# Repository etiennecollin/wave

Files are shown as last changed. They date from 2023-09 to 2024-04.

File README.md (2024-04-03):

# Wave <!-- omit from toc -->

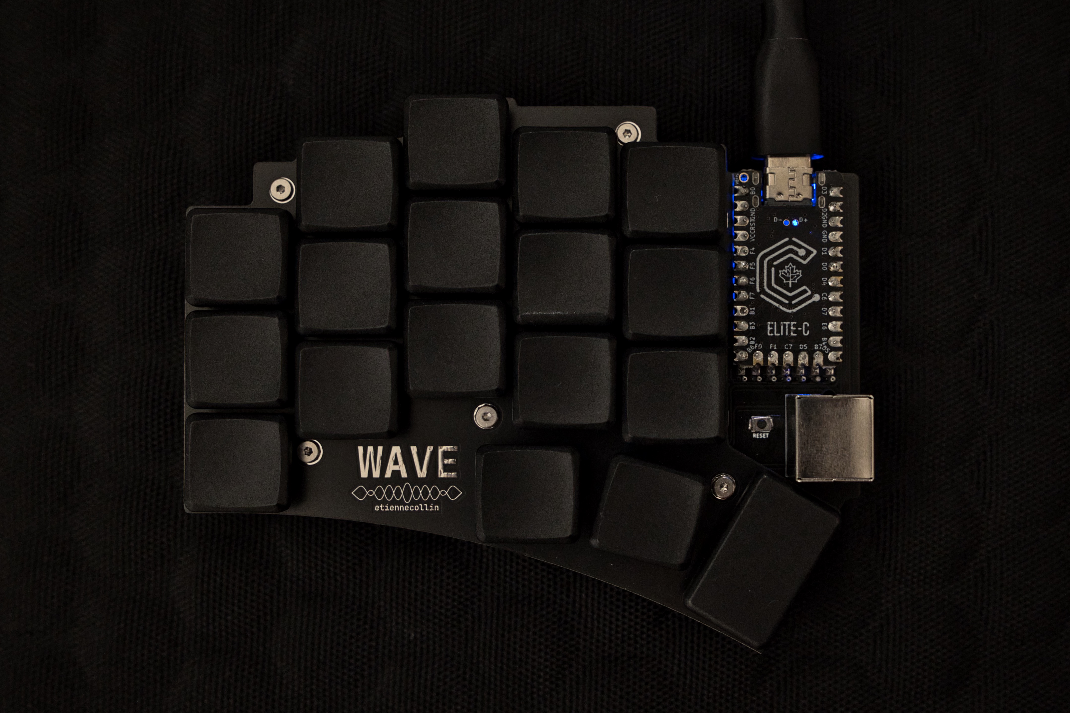
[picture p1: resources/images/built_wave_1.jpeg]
Wave v0.0.1 + MBK Blank Keycaps Image
 <sub>Wave v0.0.1 + MBK Blank Keycaps</sub>

<span>
    <a href="https://github.com/etiennecollin/wave/commits">
        
    </a>
    <a href="https://github.com/etiennecollin/wave/releases/latest">
        
    </a>
    <a href="https://github.com/etiennecollin/wave/blob/main/LICENSE">
        
    </a>
    <a href="https://github.com/qmk/qmk_firmware/tree/master/keyboards/etiennecollin/wave">
        
    </a>
</span>

---

- [What Is It](#what-is-it)
- [Features](#features)
- [Components List](#components-list)
  - [Keyboard](#keyboard)
  - [Plates Kit](#plates-kit)
- [Ordering the PCBs](#ordering-the-pcbs)
  - [Keyboard](#keyboard-1)
  - [Plates kit](#plates-kit-1)
    - [Switch Plates](#switch-plates)
    - [Back Plates](#back-plates)
- [QMK Firmware](#qmk-firmware)

## What Is It

The Wave is a small, minimalist, reversible keyboard inspired by the [Ferris](https://github.com/pierrechevalier83/ferris), the [Ferris Sweep](https://github.com/davidphilipbarr/Sweep), the [Swoop](https://github.com/jimmerricks/swoop), the [Sweep36](https://github.com/sadekbaroudi/sweep36), the [Piantor](https://github.com/beekeeb/piantor) and the [Chocofi](https://github.com/pashutk/chocofi) (thank you to the amazing creators of these keyboards). It aims to put together everything I like about these other models and to solve a few issues I found with them.

## Features

- Choc V1 switches
  - The switches can be soldered, or hot swapped using either Mill-Max or Kailh hot swap sockets
- Choc spacing (supports MBK keycaps)
- The same column stagger you loved on the [Ferris Sweep](https://github.com/davidphilipbarr/Sweep)
- 1.5u thumb key support
- Diode-less build
- Reversible PCB
- USB-C
- Mini DIN 4 (S-Video) connector used to connect both halves of the keyboard
  - The issue with TRRS connectors is that [they are not hot swap](https://docs.qmk.fm/#/feature_split_keyboard?id=considerations); disconnecting the cable while the keyboard is powered via usb risks damaging/breaking the controller by shorting the VCC pin to a GND or data pin.
  - The Mini DIN 4 connector solves this issue and is readily available on the market, being the cable used for S-Video.
- Switch plate and back plate available
- No LEDs

## Components List

### Keyboard

Here are the **required** components to build the Wave:

- 2x Keyboard PCBs (PCB manufacturers usually sell them in multiples of 5)
- 2x Elite-C V4 controllers
- 36x Choc V1 switches
- 36x MBK compatible keycaps
- 2x Mini DIN 4 Jack ([MDJ-004-FS](https://www.digikey.ca/en/products/detail/adam-tech/MDJ-004-FS/9832525))
- 1x Mini DIN 4 (S-Video) cable
- 1x USB-C Cable to connect to computer

Here are the **optional** components to build the Wave:

- Hot swap sockets, either:
  - 36x Kailh hot swap sockets for Choc switches
  - 72x Mill-Max hot swap sockets (preferably [3305](https://www.digikey.ca/en/products/detail/mill-max-manufacturing-corp/3305-1-15-15-47-27-10-0/13901953) or [7305](https://www.digikey.ca/en/products/detail/mill-max-manufacturing-corp/7305-0-15-15-47-27-10-0/1765737) sockets as they have a thinner profile)
- 2x reset switches ([B3U-1000P-B](https://www.digikey.ca/en/products/detail/omron-electronics-inc-emc-div/B3U-1000P-B/1811777))
  - The B3U-1000PM, B3U-1000P-B and B3U-1000PM-B variants will work as they have the same footprint.
- 10x Rubber feet/bumpers (I like these [RBS-12BK](https://www.digikey.ca/en/products/detail/essentra-components/RBS-12BK/3814603))

### Plates Kit

- 2x Switch plate PCBs (PCB manufacturers usually sell them in multiples of 5)
  - The switch plates may be used without back plates.
- 2x Back plate PCBs (PCB manufacturers usually sell them in multiples of 5)
  - The back plates **require** switch plates to screw into.
- 5x M2 6mm spacer ([970060244](https://www.digikey.ca/en/products/detail/w%C3%BCrth-elektronik/970060244/9488532))
- 10x M2 3mm screws ([I like these torx screws](https://www.ebay.ca/itm/154354213469?var=454428568064))

## Ordering the PCBs

### Keyboard

Wave PCB Image

<sub>Wave PCB</sub>

To order the keyboard PCB, the following settings are recommended[^1]:

| Detail | Value |
| --- | --- |
| Gerber file | `Wave_0.0.1.zip` |
| Base material | FR-4 |
| Layers | 2 |
| Different design | 1 |
| Delivery format | Single PCB |
| PCB thickness | **1.6mm** |
| PCB color | (Personal preference) |
| Silkscreen | (Personal preference) |
| Surface finish | (Personal preference)[^2] |
| Outer copper weight | 1oz |
| Via Covering | Tented |
| Board Outline Tolerance | ±0.2mm(Regular) |
| Confirm production file | No |
| Remove order number | Yes |
| Gold Fingers | No |
| Castellated holes | No |

### Plates kit

You will need to order two different PCBs; the switch plate one and the back plate one.

#### Switch Plates

Wave Switch Plate PCB Image

<sub>Wave Switch Plate PCB</sub>

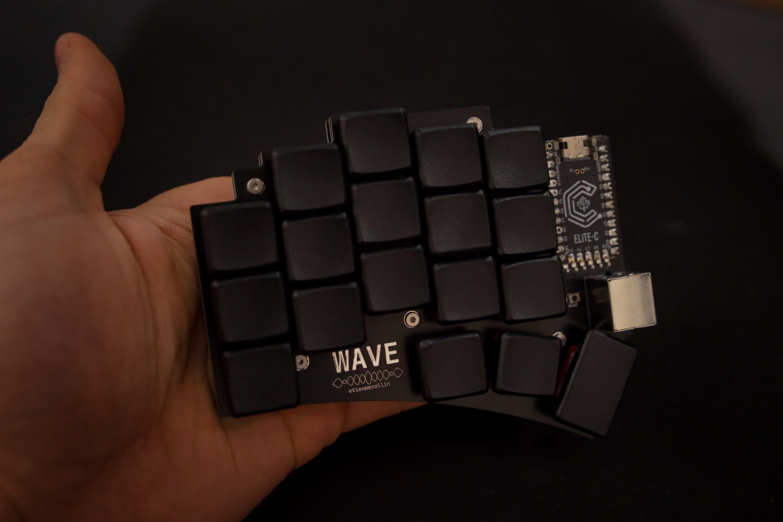
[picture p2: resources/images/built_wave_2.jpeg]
Wave v0.0.1 Switch Plate Image
 <sub>Wave v0.0.1 Switch Plate</sub>

To order the switch plate PCB, the following settings are recommended[^1]:

| Detail | Value |
| --- | --- |
| Gerber file | `Wave_Switch_Plate_0.0.1.zip` |
| Base material | FR-4 |
| Different design | 1 |
| Layers | 2 |
| Delivery format | Single PCB |
| PCB thickness | **1.2mm** |
| PCB color | (Personal preference) |
| Silkscreen | (Personal preference) |
| Surface finish | (Personal preference)[^2] |
| Outer copper weight | 1oz |
| Via Covering | Tented |
| Board Outline Tolerance | ±0.2mm(Regular) |
| Confirm production file | No |
| Remove order number | Yes |
| Gold Fingers | No |
| Castellated holes | No |

#### Back Plates

Wave Back Plate PCB Image

<sub>Wave Back Plate PCB</sub>

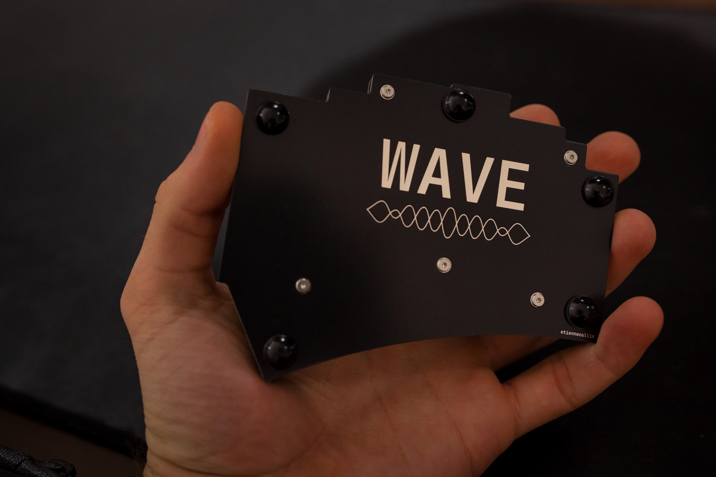
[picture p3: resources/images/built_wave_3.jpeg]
Wave v0.0.1 Back Plate Image
 <sub>Wave v0.0.1 Back Plate</sub>

To order the back plate PCB, the following settings are recommended[^1]:

| Detail | Value |
| --- | --- |
| Gerber file | `Wave_Back_Plate_0.0.1.zip` |
| Base material | FR-4 |
| Different design | 1 |
| Layers | 2 |
| Delivery format | Single PCB |
| PCB thickness | **1.6mm** |
| PCB color | (Personal preference) |
| Silkscreen | (Personal preference) |
| Surface finish | (Personal preference)[^2] |
| Outer copper weight | 1oz |
| Via Covering | Tented |
| Board Outline Tolerance | ±0.2mm(Regular) |
| Confirm production file | No |
| Remove order number | Yes |
| Gold Fingers | No |
| Castellated holes | No |

## QMK Firmware

The [latest firmware](https://github.com/qmk/qmk_firmware/tree/master/keyboards/etiennecollin/wave) can be found on the official [QMK](https://github.com/qmk/qmk_firmware/tree/master) repository.

<a href="(https://github.com/qmk/qmk_firmware/tree/master/keyboards/etiennecollin/wave">
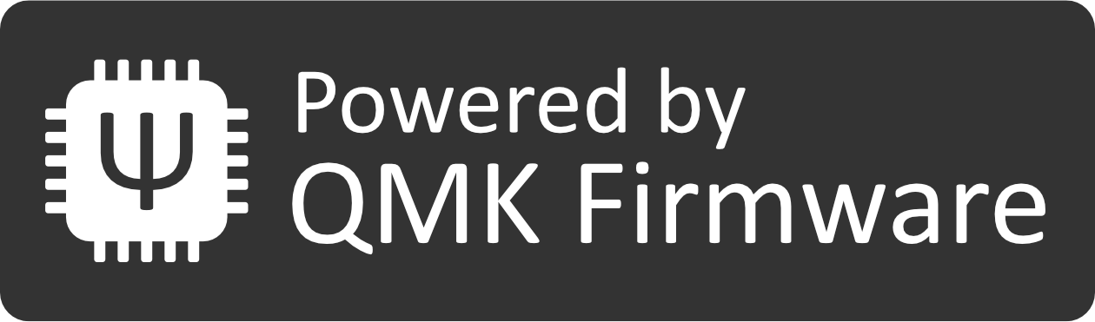
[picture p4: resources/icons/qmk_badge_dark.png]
    
</a>

[^1]: Settings are for [JLCPCB](https://jlcpcb.com/), but should be similar with other manufacturers.
[^2]: ROHS or lead-free options should be preferred (LeadFree HASL).

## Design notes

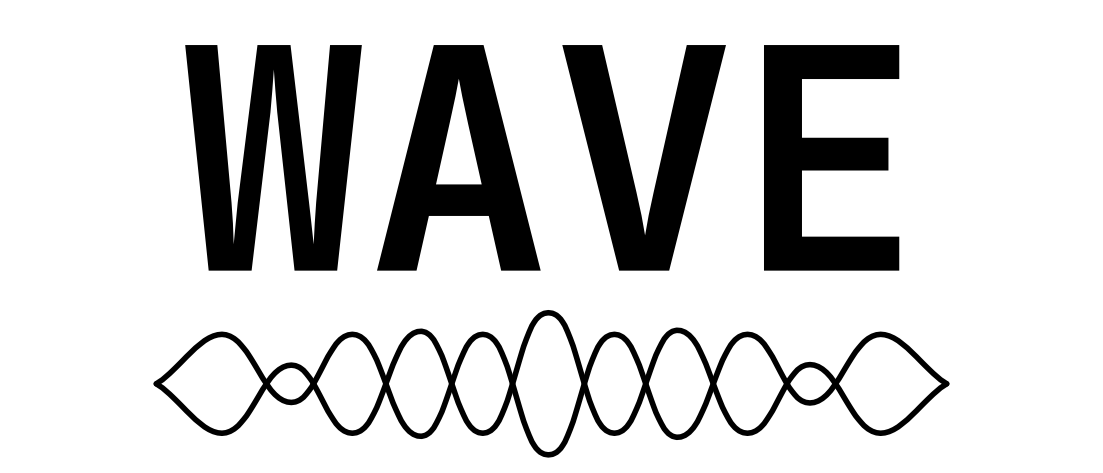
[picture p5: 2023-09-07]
resources/icons/wave_big.png

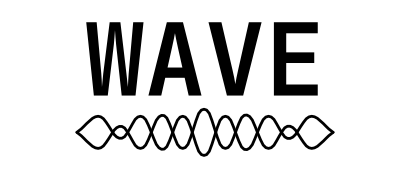
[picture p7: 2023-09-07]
resources/icons/wave.png

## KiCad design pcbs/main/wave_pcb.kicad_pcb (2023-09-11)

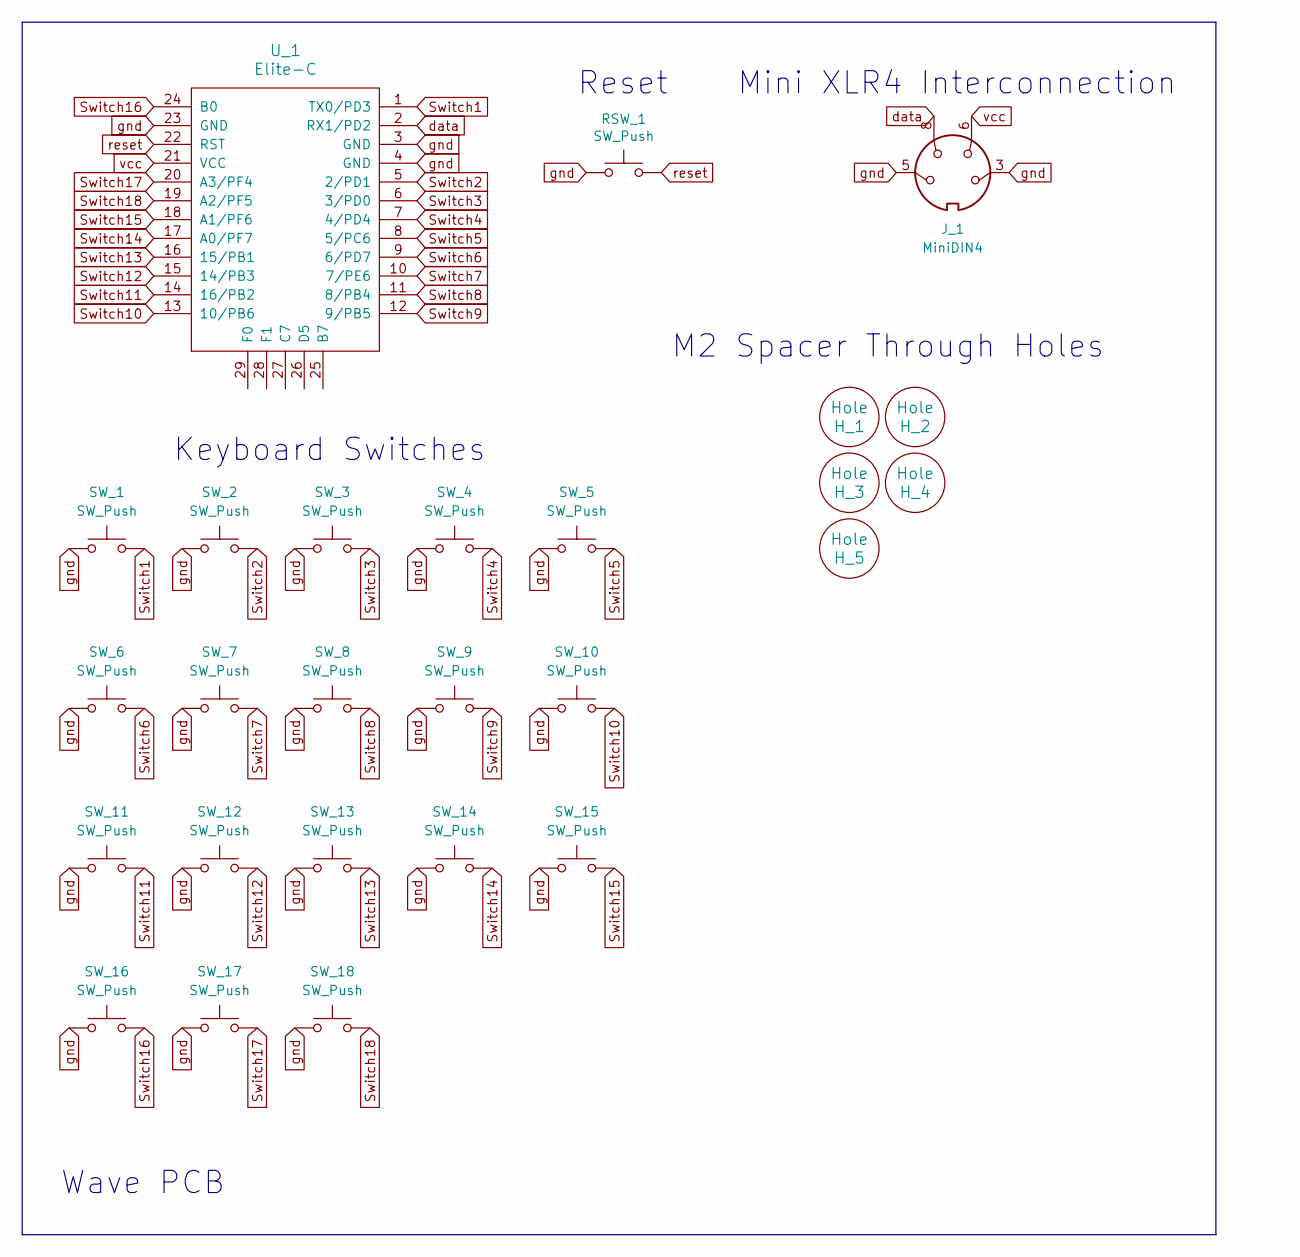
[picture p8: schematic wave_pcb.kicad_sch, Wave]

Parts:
H_1, H_2, H_3, H_4, H_5: Hole; Würth_Elektronik_970060244_M2_spacer_hole_pad
J_1: MiniDIN4; AdamTech_MDJ-004-FS_reversible
RSW_1: SW_Push; Omron_B3U-1000P-B_reversible
SW_1, SW_2, SW_3, SW_4, SW_5, SW_6, SW_7, SW_8, SW_9, SW_10, SW_11, SW_12, SW_13, SW_14, SW_15, SW_17, SW_18: SW_Push; Kailh_socket_PG1350_1.00u_optional_millmax_reversible
SW_16: SW_Push; Kailh_socket_PG1350_1.50u_optional_millmax_reversible
U_1: Elite-C; Elite-C-upsideDown_reversible

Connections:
Switch1: SW_1.1, U_1.1 (TX0/PD3)
Switch2: SW_2.1, U_1.5 (2/PD1)
Switch3: SW_3.1, U_1.6 (3/PD0)
Switch4: SW_4.1, U_1.7 (4/PD4)
Switch5: SW_5.1, U_1.8 (5/PC6)
Switch6: SW_6.1, U_1.9 (6/PD7)
Switch7: SW_7.1, U_1.10 (7/PE6)
Switch8: SW_8.1, U_1.11 (8/PB4)
Switch9: SW_9.1, U_1.12 (9/PB5)
Switch10: SW_10.1, U_1.13 (10/PB6)
Switch11: SW_11.1, U_1.14 (16/PB2)
Switch12: SW_12.1, U_1.15 (14/PB3)
Switch13: SW_13.1, U_1.16 (15/PB1)
Switch14: SW_14.1, U_1.17 (A0/PF7)
Switch15: SW_15.1, U_1.18 (A1/PF6)
Switch16: SW_16.1, U_1.24 (B0)
Switch17: SW_17.1, U_1.20 (A3/PF4)
Switch18: SW_18.1, U_1.19 (A2/PF5)
data: J_1.8, U_1.2 (RX1/PD2)
gnd: J_1.3, J_1.5, RSW_1.1, SW_1.2, SW_2.2, SW_3.2, SW_4.2, SW_5.2, SW_6.2, SW_7.2, SW_8.2, SW_9.2, SW_10.2, SW_11.2, SW_12.2, SW_13.2, SW_14.2, SW_15.2, SW_16.2, SW_17.2, SW_18.2, U_1.3 (GND), U_1.4 (GND), U_1.23 (GND)
reset: RSW_1.2, U_1.22 (RST)
vcc: J_1.6, U_1.21 (VCC)

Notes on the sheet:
Keyboard Switches
Mini XLR4 Interconnection
M2 Spacer Through Holes
Wave PCB
Reset

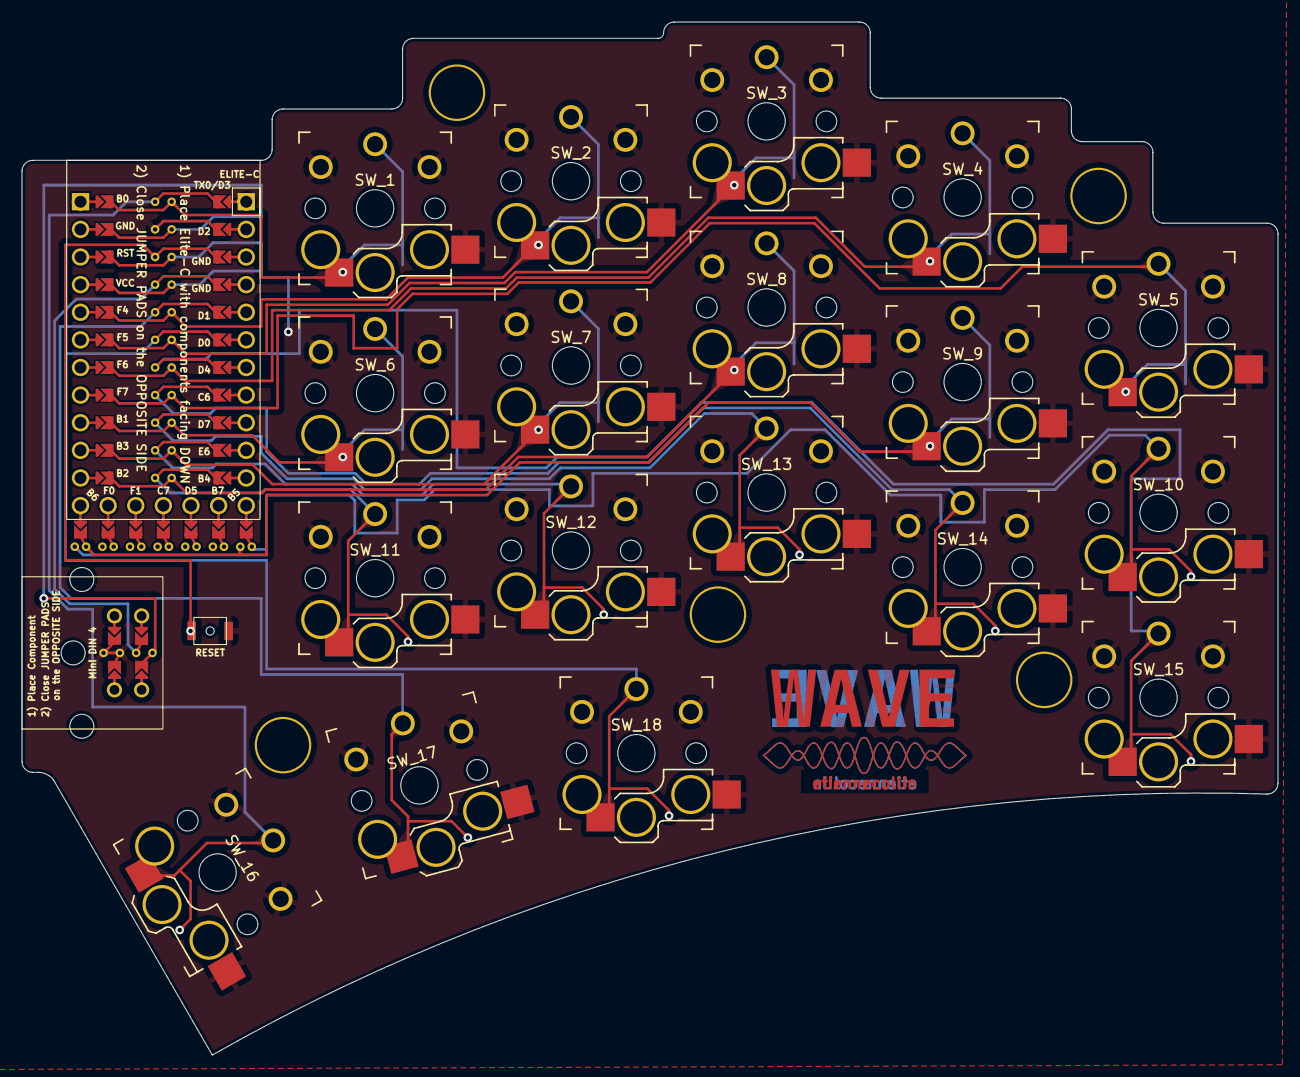
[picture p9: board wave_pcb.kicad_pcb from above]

Board: 2 copper layers, 115.5 x 95.0 mm, 28 parts (0 on the bottom side), 22 nets.

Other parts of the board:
LOGO***: logo_wave_back; logo_wave
name: logo_username

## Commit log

2023-09-07 Created main PCB
    [wave_pcb-rounded.kicad_pcb, wave_pcb.kicad_pcb, wave_pcb.kicad_sch]
2023-09-07 Created back plate
    [back_plate_pcb.kicad_pcb, back_plate_pcb.kicad_sch]
2023-09-07 Created switch plate
    [switch_plate_pcb.kicad_pcb, switch_plate_pcb.kicad_sch]
2023-09-07 Added PCB renders
2023-09-11 Fixed spacing of PCB edges
    [back_plate_pcb.kicad_pcb, switch_plate_pcb.kicad_pcb, wave_pcb-rounded.kicad_pcb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]
2023-09-12 Specified Mini DIN 4 cable use
2023-09-12 Added links to Mill Max sockets
2023-09-12 Updated PCB renders

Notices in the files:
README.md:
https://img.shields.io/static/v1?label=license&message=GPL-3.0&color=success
